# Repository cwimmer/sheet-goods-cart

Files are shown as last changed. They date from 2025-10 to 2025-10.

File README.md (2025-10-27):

# Sheet Goods Cart

This cart is designed to mange quarter sheets as well as larger cutoffs in a small shop.  It is composed of commodity aluminum extrusions, casters, and joining plates.  It is not designed to hold full 4x8 sheets.

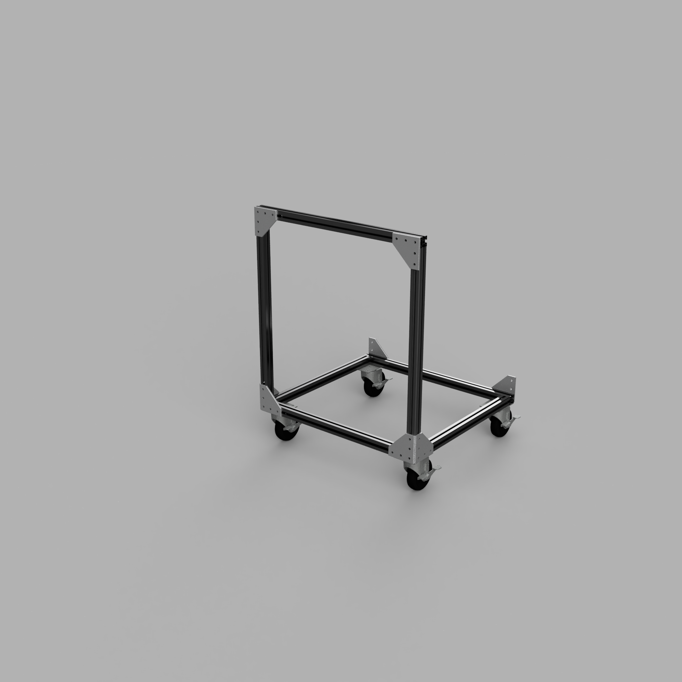
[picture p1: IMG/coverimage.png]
A completed sheet goods cart made from aluminum extrusions showing the wheeled base frame with vertical handle assembly, designed to transport quarter sheets and lumber cutoffs in a workshop setting


Please use the [latest released version](https://github.com/cwimmer/sheet-goods-cart/releases/latest).  The main branch might have partial changes committed.

## Tools and Skills required

- Metric hex wrenches
- Large square
- Metric ruler (600mm or longer)

## Table of Contents

- [Readme](README.md) - This file
- [Bill of Materials](BOM.md) - Specifications of parts included in this assembly
- [Assembly Instructions](ASSEMBLY.md) - Assembly Instructions
- [Changelog](CHANGELOG.md) - Chronologically ordered list of notable changes for each version of a project
- [Material Defaults](MATERIAL_DEFAULTS.md) - Descriptions of materials where not otherwise specified.
- [On Suppliers](ON_SUPPLIERS.md) - Discussion of how to source parts for this assembly
- [Acknowledgements](ACKNOWLEDGEMENTS.md) - Acknowledgements of other authors included either for reference or inspiration

## General Notes

1. Unless otherwise specified, dimensions are in millimeters.
2. The CAD diagrams in the CAD directory are the authoritative definition of this assembly.

## License

Unless otherwise noted:

- **All written content and images:** © Charles Wimmer, licensed under [Creative Commons Attribution 4.0 International](https://creativecommons.org/licenses/by/4.0/).
- **All hardware design files (e.g., STL, CAD, PCB):** Licensed under the [CERN Open Hardware License v2 – Strongly Reciprocal](https://ohwr.org/cern_ohl_s_v2.txt).
- **All code and scripts:** Licensed under the [MIT License](https://opensource.org/licenses/MIT).

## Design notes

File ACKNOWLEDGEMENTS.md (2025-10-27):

# Acknowledgements

- [Caster](https://www.mcmaster.com/8789t42/) model by McMaster
- [Extrusion](https://www.mcmaster.com/5537T902/) model by McMaster
- [L Bracket](https://www.mcmaster.com/5537T963/) model by McMaster

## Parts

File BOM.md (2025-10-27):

# Bill of Materials

Most components are listed from McMaster for convenience; feel free to substitute equivalent items from other suppliers.

## Non-fasteners

| Part Number | Common Name | Quantity | Description | Material | Finish | Sources | Notes |
| --- | --- | --- | --- | --- | --- | --- | --- |
| SG-101 | 600mm Aluminum Extrusions | 5| 3030 t-slot aluminum extrusion| Aluminum alloy (Magnesium and Silicon 6xxx ) |Any|McMaster: [5537T902](https://www.mcmaster.com/5537T902/)<br>Amazon US: [B0D8VF795H](https://www.amazon.com/dp/B0D8VF795H)|  |
| SG-102 | 500mm Aluminum Extrusions | 2 | 3030 t-slot aluminum extrusion |Aluminum alloy (Magnesium and Silicon 6xxx ) |Any|McMaster: [5537T902](https://www.mcmaster.com/5537T902/)<br>Amazon US: [B0D8VBJ238](https://www.amazon.com/dp/B0D8VBJ238)| |
| SG-103 | L Brackets | 8 | 90 Degree Surface Bracket for 30 mm High Rail | Aluminum alloy (Magnesium and Silicon 6xxx )|Any|McMaster: [5537T963](https://www.mcmaster.com/5537T963/)<br>Amazon US: [B0C16ZR1XD](https://www.amazon.com/dp/B0C16ZR1XD) |  |
| SG-104| Casters | Locking Swivel Casters 400lb | Swivel with Brake and 4" Diameter Blue Polyurethane Wheel |Polyurethane and Zinc coated steel | Any| McMaster: [8789t42](https://www.mcmaster.com/8789t42/)<br>Amazon: [B07PG4BZYG](https://www.amazon.com/dp/B07PG4BZYG) | |

## Fasteners

| Part Number | Common Name | Quantity | Description | Material | Finish | Sources | Notes |
| --- | --- | --- | --- | --- | --- | --- | --- |
| **M6** |||||
|SG-201 | M6 x 10mm SHCS |52| M6 x 1.0mm thread Stainless Steel Socket Head Cap Screws |18-8 or 304 Stainless Steel |Any|McMaster: [91292A441](https://www.mcmaster.com/91292A441/)<br>Bolt Depot: [6685](https://boltdepot.com/Product-Details?product=6685) | |
| SG-202 | M6 Washer | 12 |M6 General Purpose Washers |18-8 or 304 Stainless Steel |Any|McMaster: [93475A250](https://www.mcmaster.com/93475A250/)<br>Bolt Depot: [4516](https://boltdepot.com/Product-Details?product=4516) |  |
| SG-203 | 3030 M6 Drop inNuts | 52 |3030 M6 Drop-in Hammer Nut for 30 mm High Rail, M6 Thread | Carbon Steel or Stainless Steel |Any|McMaster: [6000N13](https://www.mcmaster.com/6000N13/) |  |

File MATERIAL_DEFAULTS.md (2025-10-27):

# Material Defaults

These are the default materials unless otherwise noted.

1. Threads: Metric Coarse unless otherwise specified. (internal 6H / extneral 6g)
2. Aluminum: Clear anodized by defauilt.  COTS as supplied or Type II Clear for custom metal.
3. FDM Parts: As-printed finish; ±0.3 mm OR ±0.5% (LARGER GOVERNS) for features
4. Edges: Remove burrs/debris.  Break all sharp edges 0.2-0.4mm.
5. Printed Parts: Emboss/Deboss part number and revision.

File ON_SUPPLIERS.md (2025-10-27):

# On Components and Suppliers

## Suppliers

In the Bill of Materials, I sometimes list McMaster as the supplier.  You do not have to purchase the components from McMaster.  McMaster provides excellent specifications for all of their components.  McMaster links are an easy way to access specifications. You may select equivalent parts from any supplier.

When McMaster does not supply a specific part, I've included links to suppliers I've used.  These parts will fulfill the requirements of this design, but you may select equivalent parts from any supplier.

## Materials

### Fasteners

I've specified stainless steel fasteners.  You may choose any material you wish for your fasteners as long as you weigh the material change against your load requirements.

## Standards

All fasteners I've used in my testing conform to ISO 4762.

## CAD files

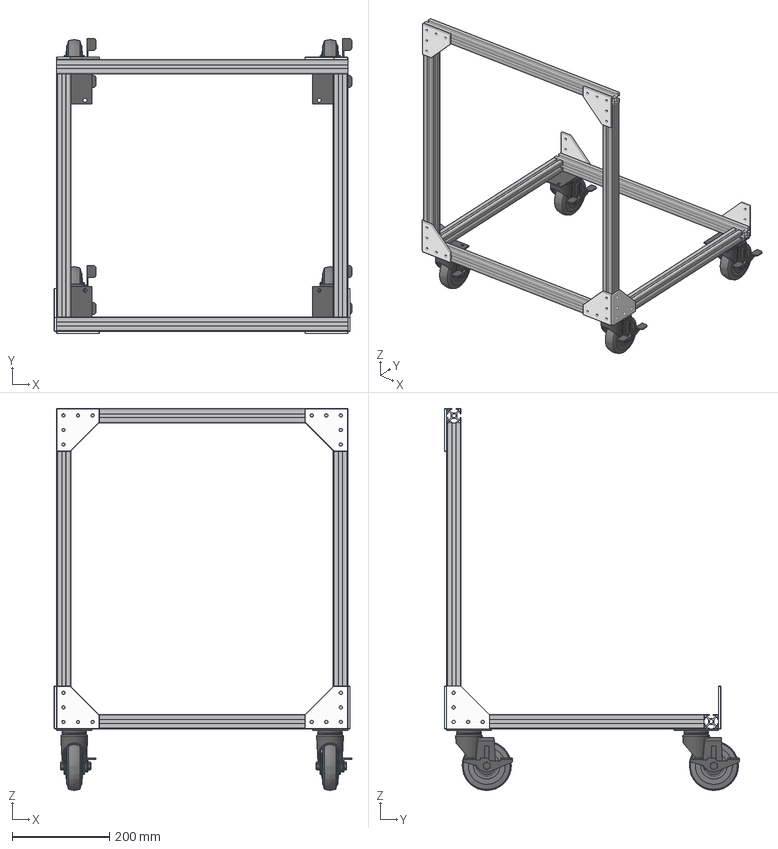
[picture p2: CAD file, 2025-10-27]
STEP/Sheet Goods Storage v1 v3.step
613.5 x 608.8 x 787.0 mm
3030 - Beam_1 x 5
3030 - Beam x 2
8789T42_Cart-King Caster x 4
5537T963_T-Slotted Framing x 8

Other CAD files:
CAD/Sheet Goods Storage v1 v3.f3z

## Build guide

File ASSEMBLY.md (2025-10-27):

# Assembly Instructions

Refer to the [CAD](CAD) diagrams for detailed part orientation.

## Bottom frame assembly

Attach the casters to two 500mm extrusions (SG-102) and two 600mm extrusions (SG-101) as shown in the CAD diagram.  Use three drop nuts (SG-203), washers (SG-202), and M6 x 10mm screws (SG-201).
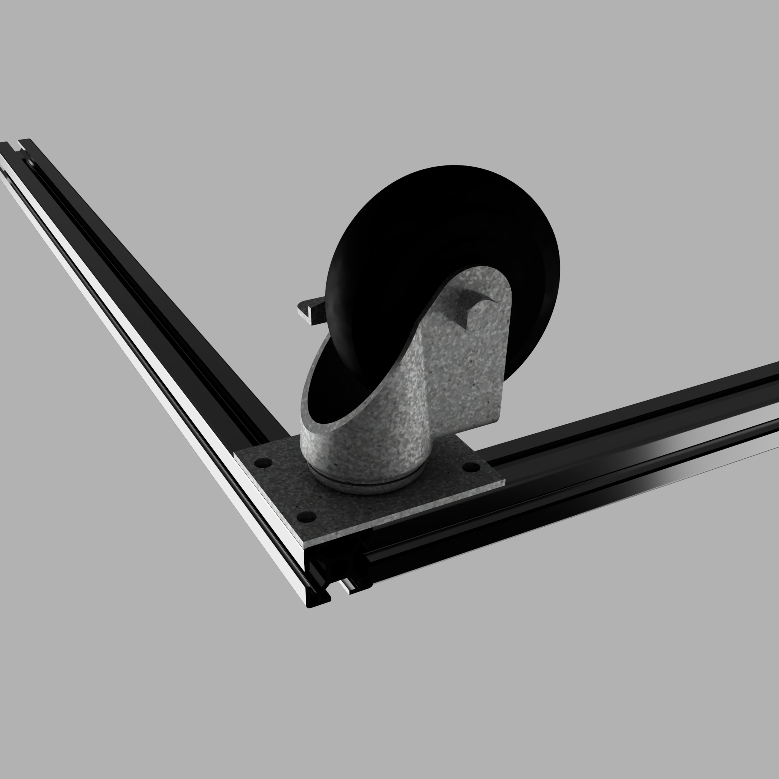
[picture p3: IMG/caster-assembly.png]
Caster Assembly

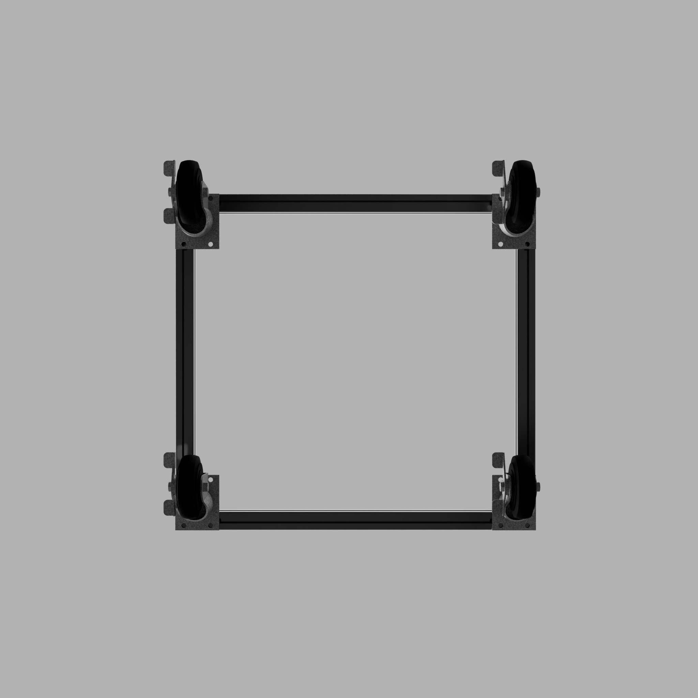
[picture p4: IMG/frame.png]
Frame


## Handle Assembly

Assemble the handle using three 600mm extrusions (SG-101) and two joining plates (SG-103) as shown in the CAD diagram.  Use drop nuts (SG-203) and M6 x 10mm (SG-201) screws to attach the joining plates.
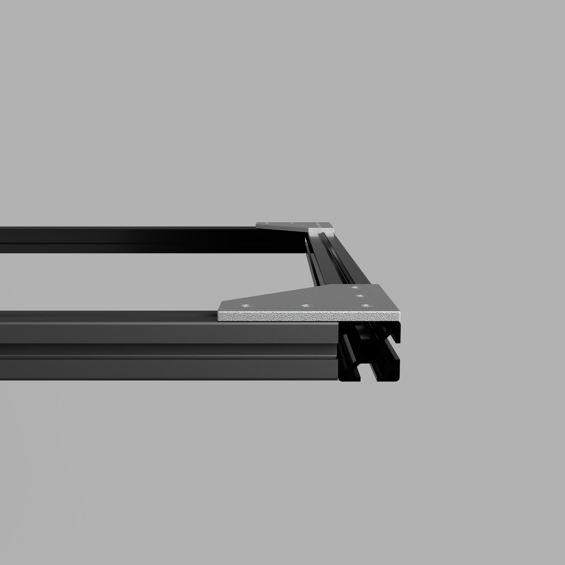
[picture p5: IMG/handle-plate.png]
Handle Plate

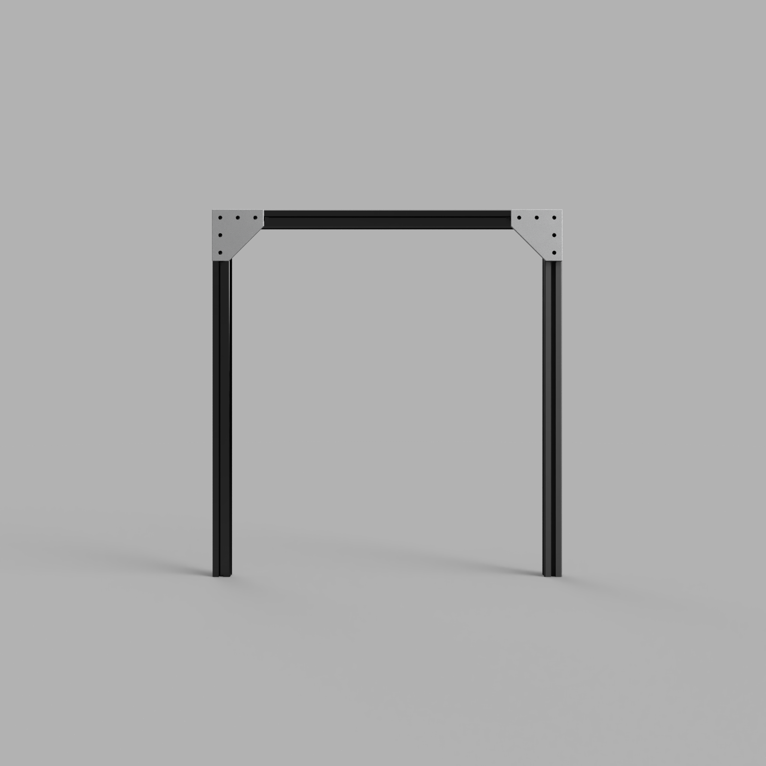
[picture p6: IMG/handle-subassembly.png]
Handle Subassembly


## Handle to Frame

Attach four joining plates (SG-103) to the bottom frame as shown in the CAD Diagram.  Then attach the handle to the four joining plates.  Use drop nuts (SG-203) an M6 x 10mm screws (SG-201) to attach the joining plates.
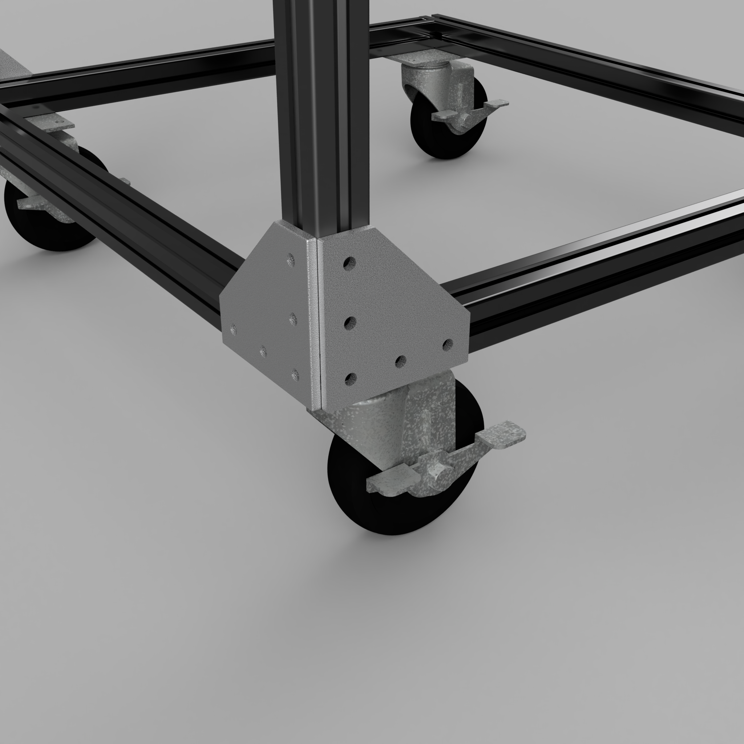
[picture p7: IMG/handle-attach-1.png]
Handle Attachment 1

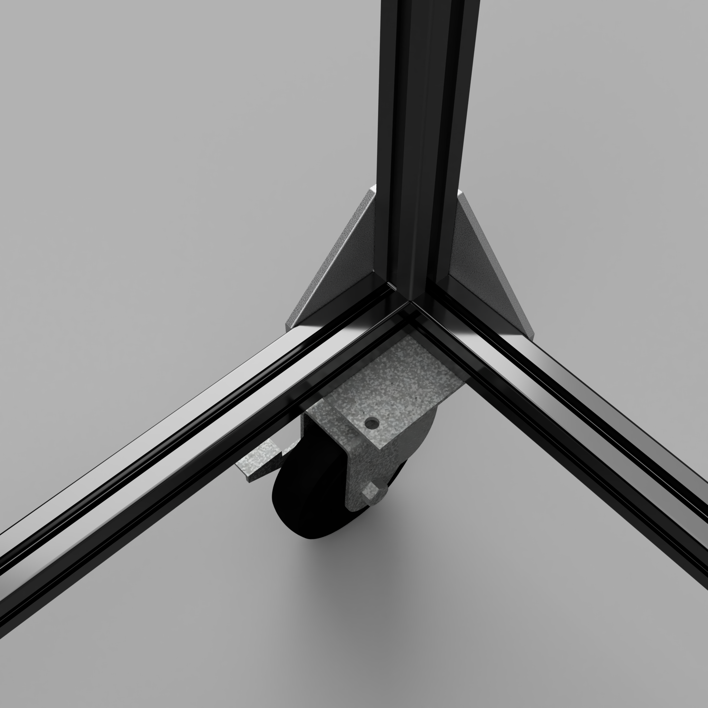
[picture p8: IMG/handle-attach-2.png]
Handle Attachment 2


## Finishing Touches

1. Attach two joining plates (SG-103) to outside rail of the frame.  These plates keep the plywood from sliding off.
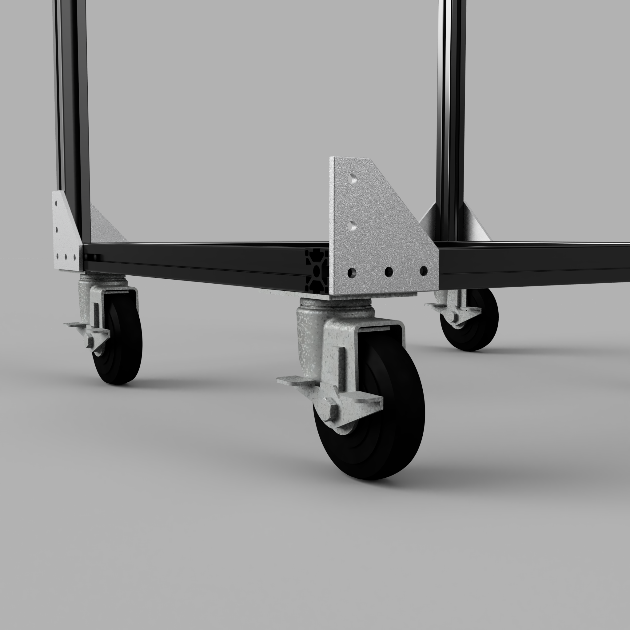
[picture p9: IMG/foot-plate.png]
Foot Plate


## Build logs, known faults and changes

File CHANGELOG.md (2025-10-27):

# Changelog

All notable changes to this project will be documented in this file.

The format is based on [Keep a Changelog](https://keepachangelog.com/en/1.1.0/).

## [Unreleased]

### Added

### Fixed

### Changed

### Removed

## [v1] - 2025-10-26

Initial Revision
